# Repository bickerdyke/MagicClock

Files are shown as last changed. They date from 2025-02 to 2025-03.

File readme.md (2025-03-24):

# Magic Clock for Home Assistant

If you ever read or saw Harry Potter, you may remember the Weasley Family's magic clock that showed the whereabouts of all family members.
And of course you wanted something like that, too.

**Good News**: I built one and can share my work with you.

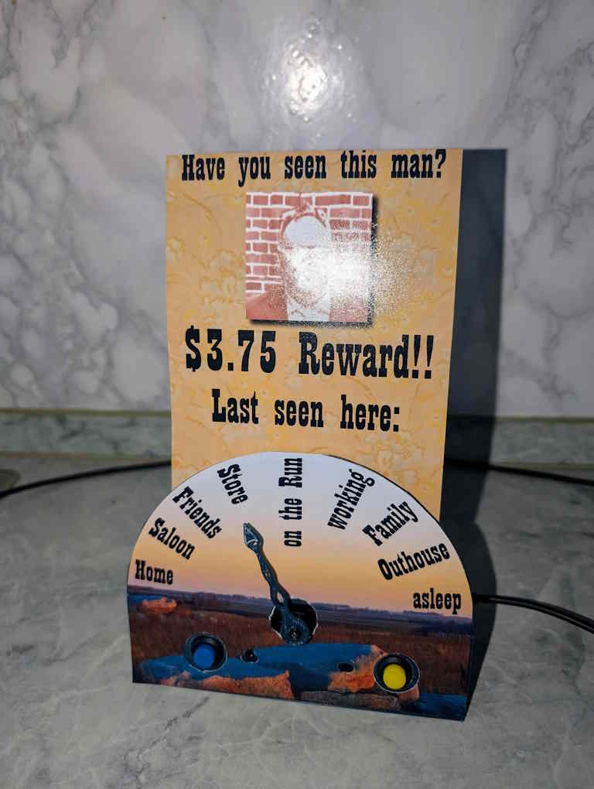
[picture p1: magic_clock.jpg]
Magic Clock Final


**Bad news**: You probably need to adjust each part of my work to your requirements. And it's several parts that need to work together.

The clock was meant to give my wive who had to go overseas for several months a way to connect back to me and home by getting live updates, but also make her presence felt by switching the living room light colors.

## Overview

This project uses a ESP32 to control a servo motor connected to a clock dial to display a persons current status. That status is based on several inputs like GPS data from phone, calendar data, a sleep state sensor or currently switched on Hue devices.

A local Home Assistant instance collects those data and decides where to point the clock dial, indicating locations like office or school, but also current activities like sleeping.

In addition, intended as a really simple way of two-way conversation, two switches control two LEDs that can be toggled on or off. The LED status is relayed back to the Home Assistant server and can be monitored and controlled from there, too.

## Requirements and Sub-Projects

It turned out that you need to combine several trades to build a magic clock. On the other hand, none of them went into the really advanced stuff and all the tools needed are free and Open Source.

- _[Smart Home Platform](homeassistant/)_: Home Assistant is used to collect all necessary data and control the clocks servo motor.
- _[CAD and 3D-Printing](CAD/)_: The case for the clock was designed using FreeCad
- _[Firmware and Network](esphome/)_: The EspHome-Project is far the easiest way to generate a firmware for ESP32 or similar that connects to Home Assistant
- _[Hardware](schematics/)_: Some sketches of the schematics
- _[Graphics & Design](Images/)_: Templates and measurements to help you designing your front plate for the magic clock. I used Scribus.

Detailed descriptions can be found in those folders.

## 3D-Printing

STL-Files for 3D-Printing the case are available on [printables.com](https://www.printables.com/model/1224639-magic-clock)

I will be happy to see your make results or comments there, too.

# Digital Twin

As an alternative to the actual clock with servo and physical dial, there is a simplified version included that uses a digital display. Building is much simpler as the only step neccessary is to clip an easily available esp32-2431S028 (or CYD - cheap yellow display) into a 3D-Printed parts (printable without any supports), flash the firmware and done. It uses a development board that contains both display and controller and the same Home Assistant back end as its "bigger" brother.

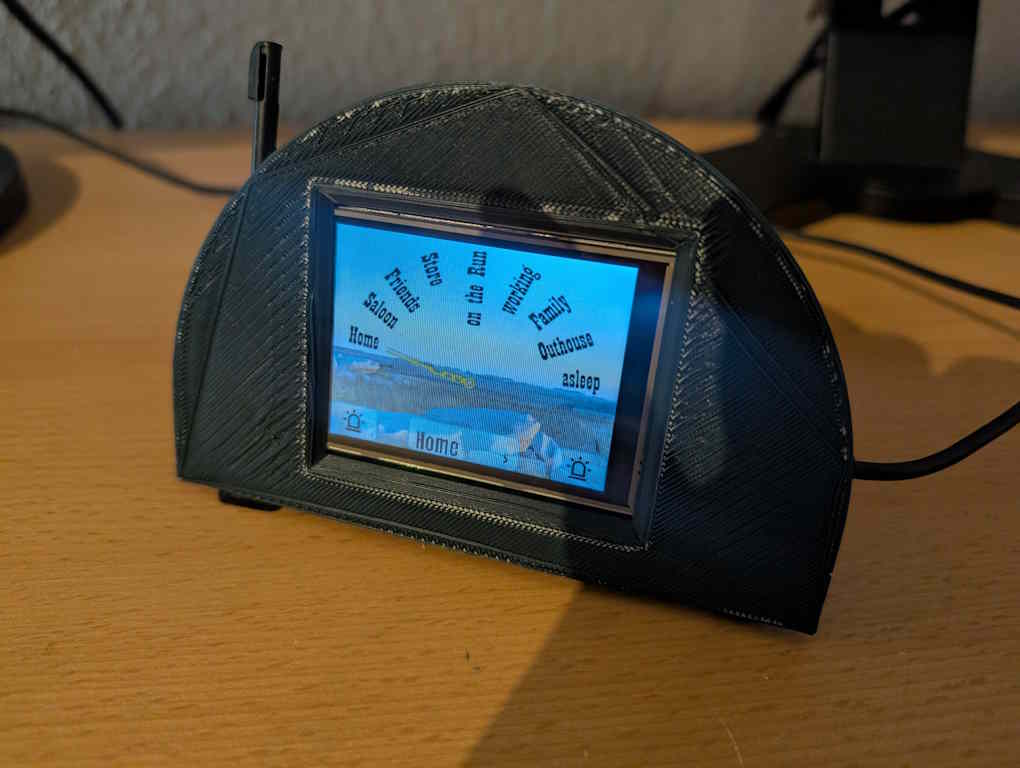
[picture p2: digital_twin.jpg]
Digital Twin


But with one exception: The included esphome configuration acts as a remote control for a "big" version. So it connects to the LED entities provided by the controlled device and has a drop down field to set the input_select entity in the backend that drives the clock hand. If you want to use _only_ a digital version you need to edit the firmware configuration to either provide entities for the two LEDs or add helpers in the back end and use those.

STL-Files for 3D-Printing the case of the digital twin are available on [printables.com](https://www.printables.com/model/1242070-magic-clock-with-display)

# Disclaimer

This is my personal hobby project and it is completely tailored to what I had already running, knew how to do or was ready to learn. Feel free to use my work as inspiration for your own and I would love to learn what you ended up making.

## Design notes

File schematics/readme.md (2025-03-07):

## Electronics

I'm very bad at electronics and soldering, so this part is probably the least complicated.

Central part is a ESP32 board. I had a ESP32 VROOM left from a previous project, but any microcontroller board that has Wifi included and is supported by [esphome](../esphome/) should do the trick.

The first prototype was working quickly:

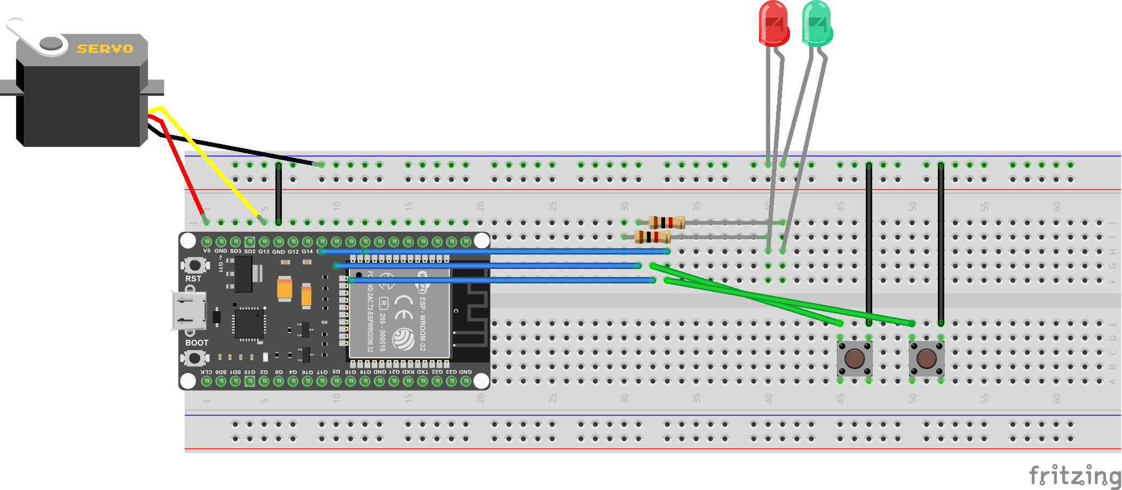
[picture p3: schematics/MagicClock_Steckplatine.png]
Breadboard sketch


A servo connected to 5V and GND for power and the PWM control to a GPIO pin that can output a PWM signal (check data sheet if using a different board) will drive the dial.

Two Buttons and two LEDs with resistors get also connected to a GPIO each. I started with 5mm LED and resistors from the junk drawer. For the final build, I used 3mm LED with integrated resistors that came with mounting rings for the case where the LEDs were supposed to click in for mounting. (50% success rate. Hot glue to the rescue!)

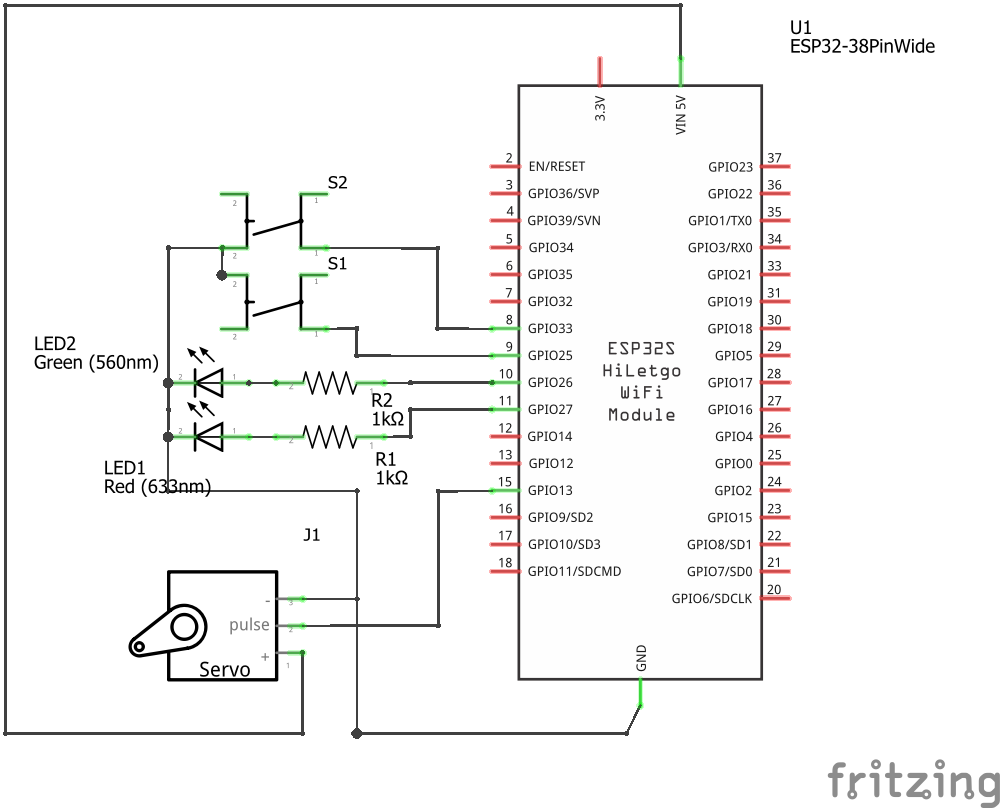
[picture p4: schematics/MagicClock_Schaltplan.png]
Circuit schematic


> [!IMPORTANT]
> I switched the GPIO pins during the assembly phase as using pins on both sides of the board made wiring easier. The pins on the schematic do not match the GPIO pins used in the final esphome configuration. You will need to adjust the configuration to whatever GPIOs you end up using.

You can find the [Fritzing](https://fritzing.org/) file included in this repo.

### Assembly

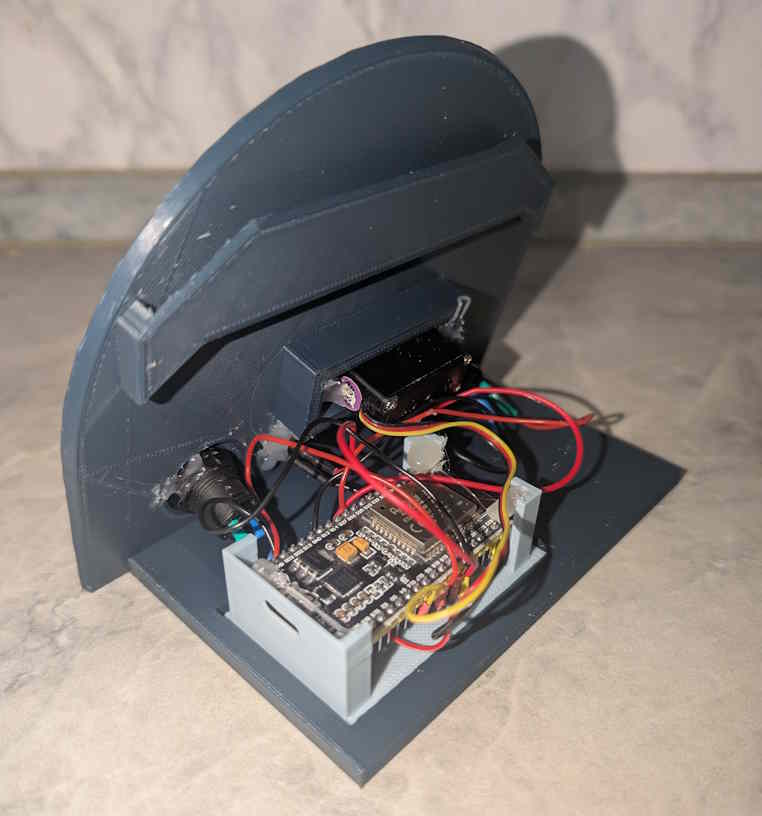
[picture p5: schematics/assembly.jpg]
Assembly


I used the terminals of the switched to connect GND for the matching LED so I only had 3 ground wires to attach to the ESP board that conveniently has the GND pins.

As mentioned in the beginning, I'm really bad at soldering so I covered up everything with the shrink tube of shame.

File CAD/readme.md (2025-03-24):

## Case design

With not much more tools than a 3d-Printer, I wanted the case to be as simple as possible and easily printable on a 15x15cm printer. Instead of a movement, I directly expose the servo motor and mount a dial on it. The clock face also needed space for the two buttons and LEDs.

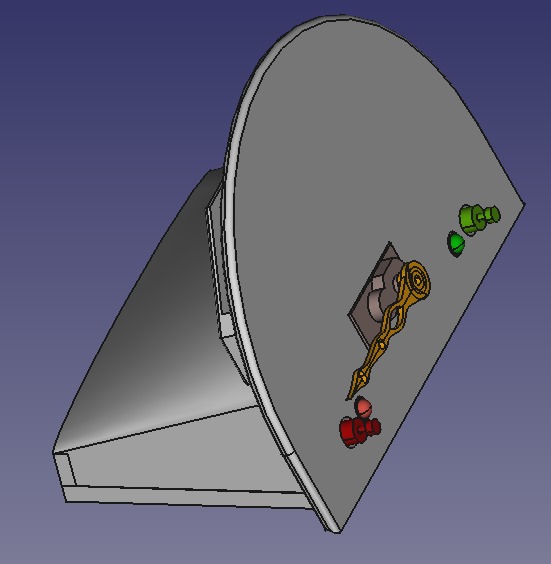
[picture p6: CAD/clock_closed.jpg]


The inside needed space to mount those things, plus the ESP board. The Board is mounted on a separate riser to simplify both printing and assembly, and maybe switch to a different type of board.

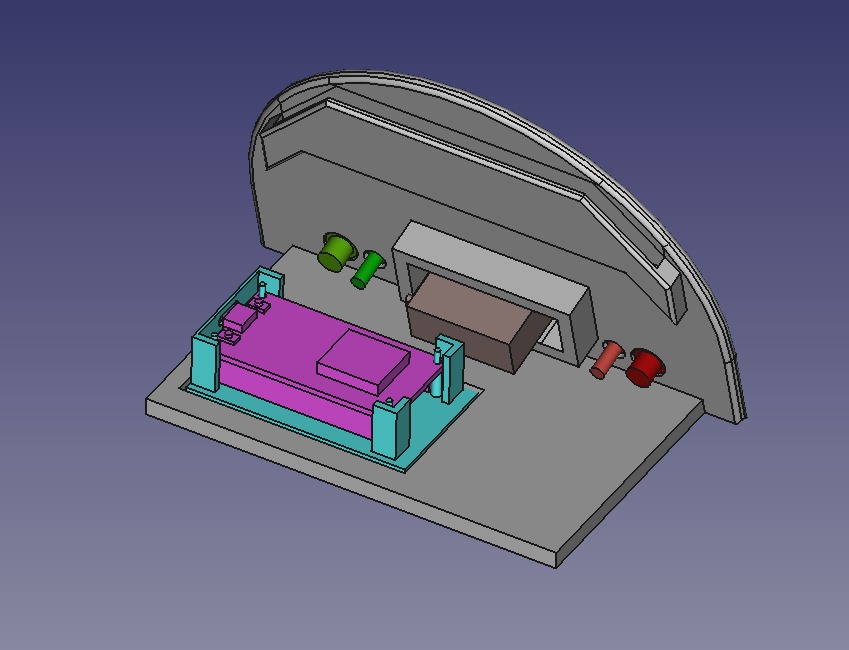
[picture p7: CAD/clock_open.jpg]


A slot to add a 11cm wide printed photo was added to the back.

### 3D Printing

Four parts need to be printed:

- Main case with clockface
- Cover
- ESP mounting plate
- Clock Dial

Case, Cover and mounting plate are simply glued together with hot glue. (Yes, _could_ have gotten a more elegant solution here...)

The Dial is screwed on the shaft of the servo using the screw that came with the motor

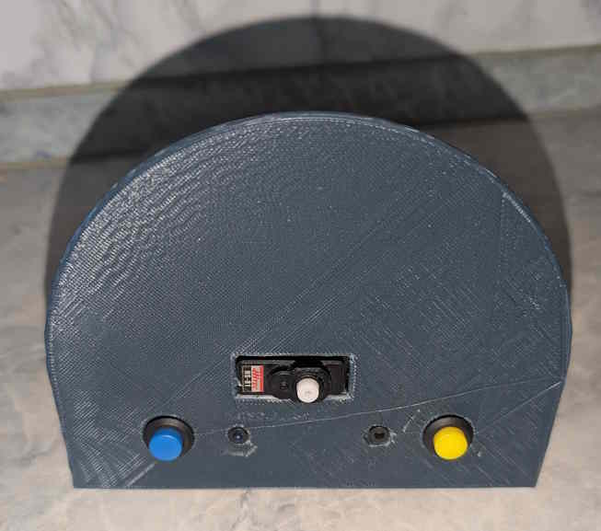
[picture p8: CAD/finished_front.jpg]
final assembly front


The front will be covered with a printed [clock face](../Images/).

## Digital Twin

It was supposed to be much smaller than the actual magic clock, but to hold the rectangular board with the display and keep the same shape as the full version, it ended up almost the same size:

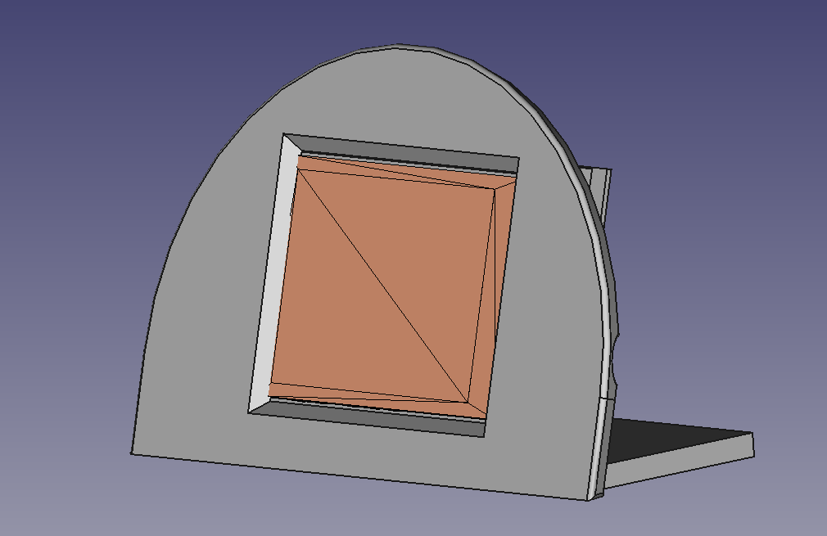
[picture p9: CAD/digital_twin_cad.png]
Digital Magic Clock CAD

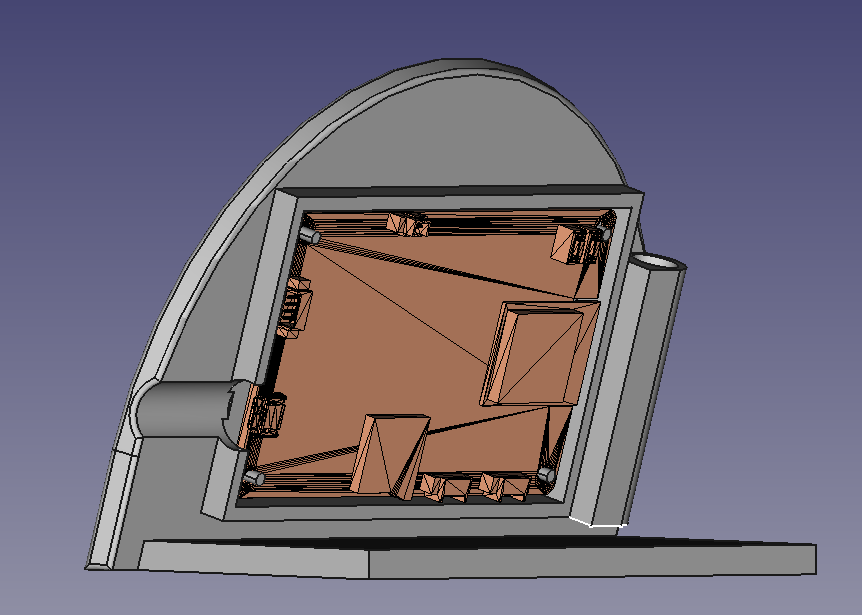
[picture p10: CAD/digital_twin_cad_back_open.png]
Digital Magic Clock CAD open


The model for the version with a digital display uses a transparent back to hold the display in place and keep the included RGB LED visible. There is also a holder for a pen that came with my display.

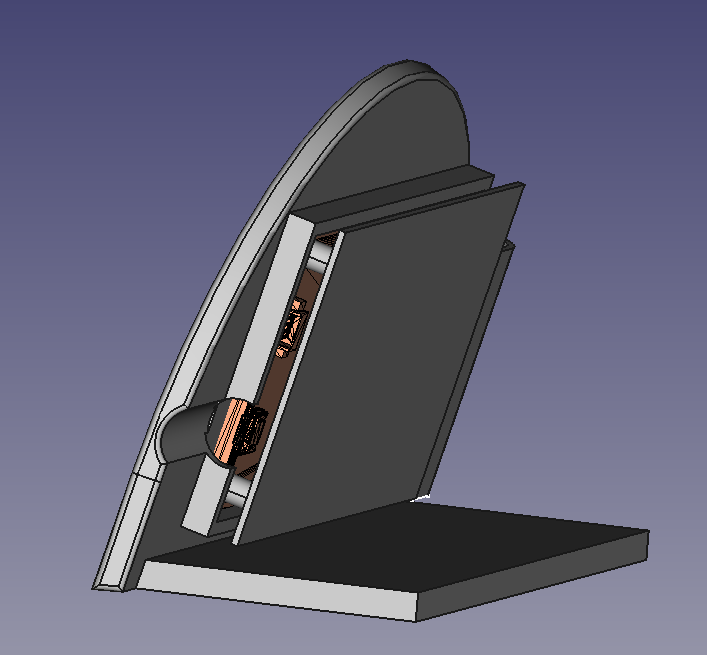
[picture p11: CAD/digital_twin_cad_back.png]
Digital Magic Clock CAD back

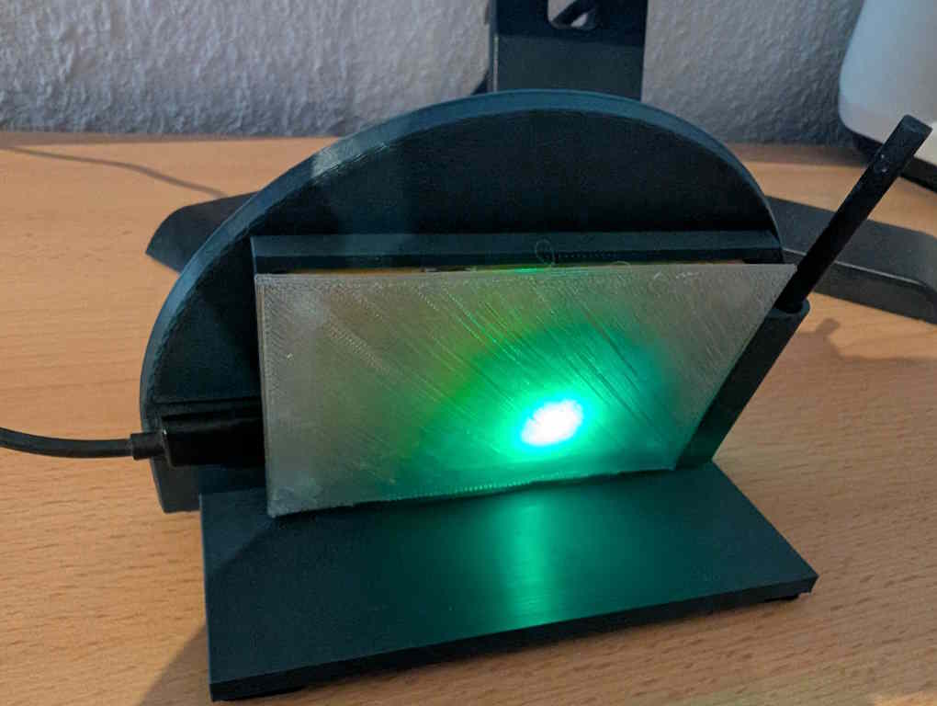
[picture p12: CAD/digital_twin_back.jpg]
Digital Magic Clock Backside


## Individual Adjustments

In case you want to do your own improvements and adjustments, I included the [FreeCAD](https://www.freecad.org/) model file in this repo. It's a free and open source CAD system.

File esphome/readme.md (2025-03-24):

## Firmware

The whole Magic Clock system is controlled by an ESP32 Wroom board with an [esphome](https://esphome.io/) firmware. It offers many features out of the box that we need:

- Servo Control
- LED / Switch Controls
- Home Assistant API support
- Wifi
- Wifi configuration in your webbrowser
- VPN

esphome takes a configuratuon file for your project and compiles a firmware for several microcontroller platforms. The configuration file for the Magic Clock is [magic-clock.yaml](magic-clock.yaml). You may need to adjust the file from this repo to your project.

### Setup

esphome can either use stores credentials to connect to a Wifi network, or, if no such network can be found, will open a configuration wifi network that you can connect to with your phone and set up your wifi. An optional password can be set in the configuration. Default configuration for the setup-wifi is ssid _Magic-Clock Setup_ with password _Foxtrott1308_

Current configuration has two slots for pre-installed wifi networks. Actual credentials will be read from a secrets.yaml file

- [Wifi configuration documentation](https://esphome.io/components/wifi.html)
- [Captive Portal documentation](https://esphome.io/components/captive_portal.html)

#### Secrets.yaml

Configuration and credentials should be kept separate. The included configuration will pull wifi and other credentials from a secrets.yaml file in the same directory as the configuration file. You can use the provided example to create your own secrets.yaml-file.

#### Home Assistant and alternatives

esphome integrates natively with Home Assistant or ioBroker.

[Home Assistant API Documentation](https://esphome.io/components/api.html) This link will also generate a random key for you that you can include in your secrets.yaml to encrypt communication between Home Assistant and the Magic Clock. Home Assistant will ask for this key, too when adding it as a device.

If you want to use some a different software stack you can also configure esphome to include a webservice or [MQTT](https://esphome.io/components/mqtt.html) connection to accept commands to set the dial to any given position.

#### Hardware configuration

As you will probably use different pins then my build, you will need to edit the configuration to match your build. You can find the documentation for those configuration sections here:

- [Status Led](https://esphome.io/components/status_led.html)
- [Switch](https://esphome.io/components/switch/) LED hardware configuration. Will be exposed to Home Assistant
- [Binary Sensor](https://esphome.io/components/binary_sensor/) Pushbuttons. Will be exposed to Home Assistant
- [Output](https://esphome.io/components/output/#output) and [Servo](https://esphome.io/components/servo.html)
- [Number](https://esphome.io/components/number/) Will be exposed to Home Assistant. Includes the logic to control the servo motor (using esphome Servo component) when this value is changed in Home Assistant.

### VPN

In my setup, the Magic Clock will not be in the same network as my Home Assistant Server. (Actually, it will be on a different continent) As Home Assistant will use the esphome integration to connect to the Magic Clock (and not the other way round), the Clock needs to be reachable for your Home Assistant server in your home network.

To solve that problem, esphome includes a client for the wireguard vpn.

My router supports giving access to my local network to external devices using the wireguard protocol, too, so I set up wireguard VPN access to my home network. The credentials and settings that I have been provided here go to the _wg_ section of the configuration file. (directly or via secrets.yaml)

See the esphome [Wireguard component](https://esphome.io/components/wireguard.html) documentation for details and peer setup guide.

If you will have the Magic Clock in the same network as your Home Assistant server, you can remove the wireguard setup by removing the _wg:_ section from the configuration.

## Installation

Behind the scenes, esphome will take your configuration file and compile an individual firmware file for your micro controller platform. This firmware needs to be programmed into your controllers firmware memory. For the first time, this requires a USB connection to your computer. Later updates can be installed Over the Air [(OTA)](https://esphome.io/components/ota/esphome.html)

The Installation guide at [https://esphome.io/guides/getting_started_hassio](https://esphome.io/guides/getting_started_hassio) will guide you through installing the esphome Device builder as a Home Assistant Plugin and create and flash your first esphome firmware. If you can't install Home Assistant pluginst, esphome can be run as a [docker container](https://esphome.io/guides/getting_started_command_line#esphome-device-builder-docker).

Both options will give you access to the esphome Device manager in your webbrowser where you can add your Magic Clock as a device and upload your individual configuration file, create a firmware file based on it and flash that file on the micro controller.

For further help on esphome check out the Guides and FAQs and tips available on the [esphome homepage](https://esphome.io/).

## Digital Twin

The esphome configuration for the digital twin is found in the file [display.yaml](display.yaml). It acts as a remote control for a "big" version. So it connects to the LED entities provided by the controlled device and has a drop down field to set the input_select entity in the backend that drives the clock hand. If you want to use _only_ a digital version you need to edit the firmware configuration to either provide entities for the two LEDs or add helpers in the back end and use those.

Also, it does _not_ include a Wireguard configuration as that device is staying within my wifi. But you can set it up in the same way as it is included in magic-clock.yaml

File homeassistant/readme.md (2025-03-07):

## Home Assistant

I had already a working Home Assistant, so it was just natural to use it as the central hub to control the magic clock.

Home Assistant can use the companion app on users phones to collect location data and access all other kind of information to factor into your magic clock and on the other end can use [esphome](../esphome/readme.md) to connect and control the clock.

When connected to the device, it will expose these entities to Home Assistant:

- A number setting that controls the angle of the clock dial. The servo has a range of 180° that is represented as a number range from -100 to 100 with 0 being the middle position.
- 2 switches representing the LEDs
- 2 binary sensors representing the buttons.

Now we can unleash the power of Home Assistant... The yaml files in this directory will show you how I did it.

### Helpers

[helper.yaml](helper.yaml) sets up an input select helper listing all the labels available on the clock face and an input boolean helper to quickly enable or disable automatic movement of the clock dial.

### Dial control

[automation_set_dial_position.yaml](automation_set_dial_position.yaml) connects the selection helper to the servo motor. Each time a new option is selected by the helper, this automation will set the angle of the servo motor accordingly. The stepping for the angle control number entity in theory should be +-100 / number of labels, but in the end depends on your clockface design. Use try and error to find out which values look good and point exactly at your labels.

[automation_set_dial_label.yaml](automation_set_dial_label.yaml) This is where the magic happens. All kind of input is used to decide which label to point to:

- GPS fencing from the companion app will result in a location based labels such as "shop", "friends" or "bar"
- Events from my Google calendar will show "Working" while in meetings
- Hue lamps switched on or off are used as a substitute presence indicator for certain rooms.
- A different (existing) status helper signals sleep or awake and general presence or absence.
  If you want to use my design and turn it into a weather station or something completely different, this is the spot where you need to change to your logic.

### Buttons and LEDs

The clock has two buttons (blue and yellow) that toggle the two LEDs next to the buttons on the clockface. (also blue and yellow) Nice but not spectacular. But we can turn that into a low level 2-way communication device:

[dashboard_signal_buttons.yaml](dashboard_signal_buttons.yaml) gives an example for how to add buttons to your Home Assistant Dashboard that will

1. Show the LED status in your dashboard
1. Allow to remote control the LEDs manually

Feel free to add any semantics to those two lights. Switch on the yellow light for "Dinner is ready" and the blue one for "call me" or whatever fits the point of your magic clock.

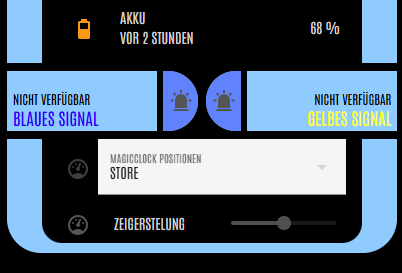
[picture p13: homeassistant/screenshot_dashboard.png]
Dasbhoard Buttons


[automation_show_clock_signal.yaml](automation_show_clock_signal.yaml) To make sure I notice when the buttons on the clock are pressed, a Hue lamp in the living room will match the color of the pressed button. Phone notifications through the Companion App or Emails or logging would go in here, too.

### Source

You can get Home Assistant at [https://www.home-assistant.io/](https://www.home-assistant.io/), but you also could use any other way of controlling the clock by using a different esphome configuration.

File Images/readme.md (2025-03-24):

## Images

The Magic Clock gets its appearance mostly from two images: The clockface and the (optional) picture in the picture holder on the back.

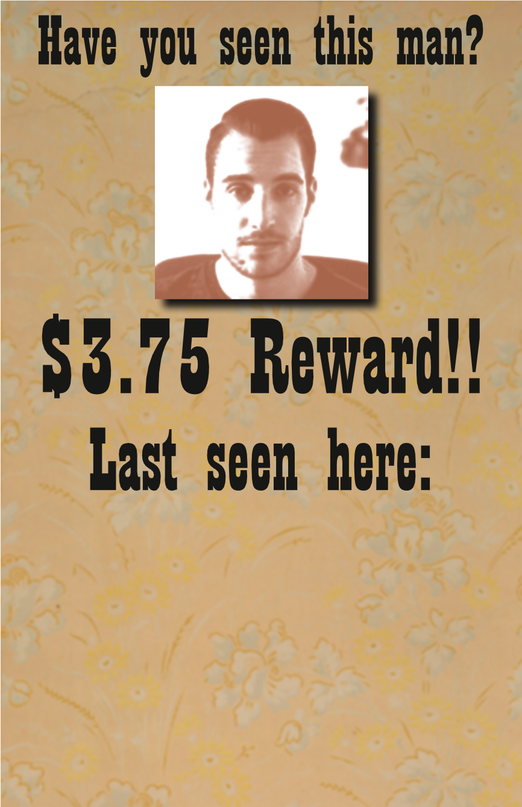
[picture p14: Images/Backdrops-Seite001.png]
Backdrop 1

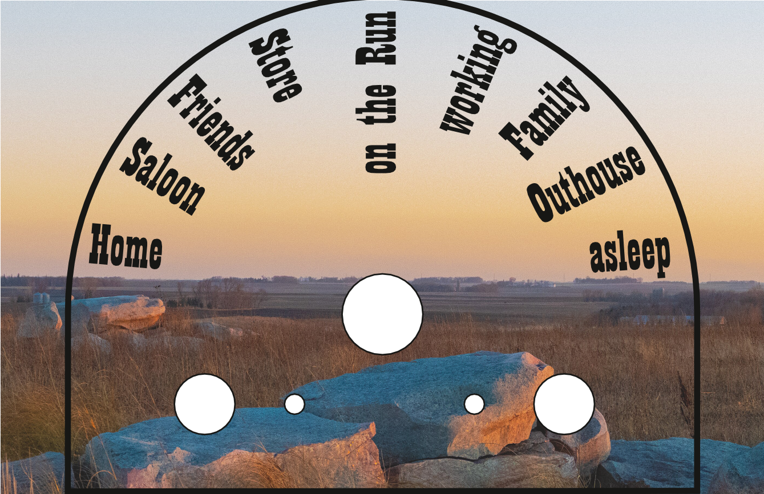
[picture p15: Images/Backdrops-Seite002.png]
Backdrop 2


Both are created as 11x17cm images that is available as a standard photo size (and can be printed out on actual photo stock) and roughly matches the 15x15cm limits of my 3d-Printer.

They were created using [Scribus](https://www.scribus.net/), free and open source DTP software, in case you want to build on my pictures and go from there.

Or if you want to use your favorite graphic suite, you can use these measurements as a guideline:

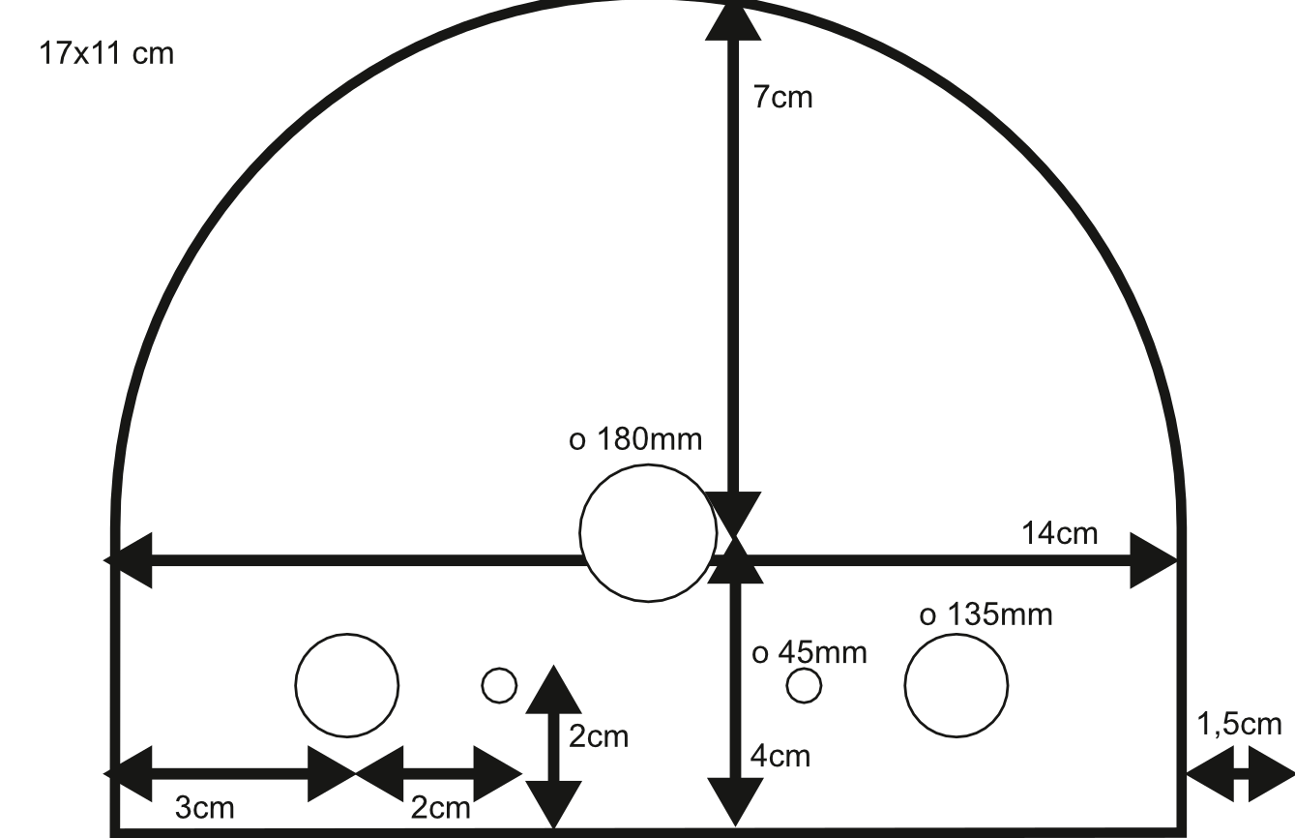
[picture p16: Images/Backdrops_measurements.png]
Measurements


### Sources

#### Font
[Playbill](https://learn.microsoft.com/de-at/typography/font-list/playbill), 75pt, part of the MSOffice package

#### Image

I used images available on Wikimedia Commons, so I won't include them in this repo. You can get them here if you want to use them, too.

* Sidewall (USA), 1905–15, Made by Janeway & Co. Inc. [2048px-Sidewall_(USA),_1905–15_(CH_18500779).jpg](https://commons.wikimedia.org/wiki/File:Sidewall_(USA),_1905%E2%80%9315_(CH_18500779).jpg) Wikemedia Commons, Public Domain

* Evening on the prairie, Rock County, Minnesota [4096px-Evening_on_the_prairie,_Rock_County,_Minnesota.jpg](https://commons.wikimedia.org/wiki/File:Evening_on_the_prairie,_Rock_County,_Minnesota.jpg) Wikimedia Commons, Creative Commons Attribution 2.0 Generic license, work by Sank63 from [https://www.flickr.com/photos/gsankary/53341044031/]

#### Dummy-User
The person used here is a dummy user profile picture created by [https://randomuser.me/photos](https://randomuser.me/photos)

### Digital Dial
The dial for the digital twin of the clock is based on [Clock2](https://commons.wikimedia.org/wiki/File:Clock2.svg) by Wikipedia-User [Fornax](https://commons.wikimedia.org/wiki/User:Fornax) licensed under the Creative Commons Attribution-Share Alike 3.0 Unported license.

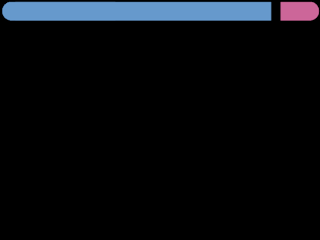
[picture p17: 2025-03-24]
esphome/images/lcars-wallpaper1.png

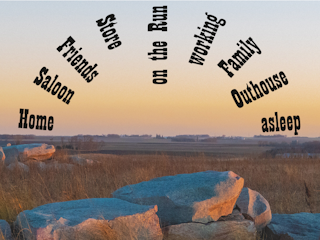
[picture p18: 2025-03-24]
esphome/images/magic-clock.png

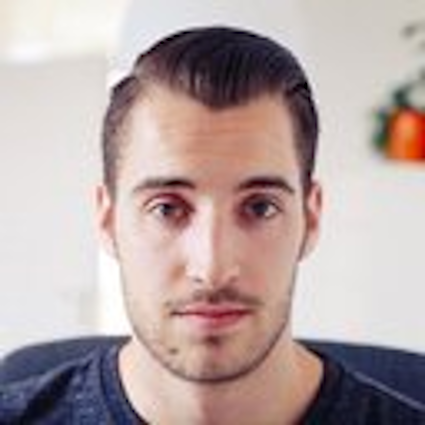
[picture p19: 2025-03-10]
Images/mugshot.jpg

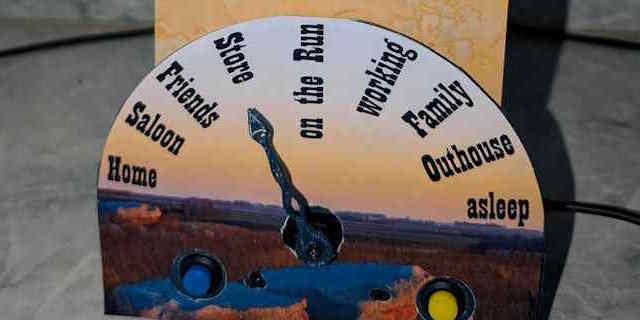
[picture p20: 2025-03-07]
magic_clock - social.jpg

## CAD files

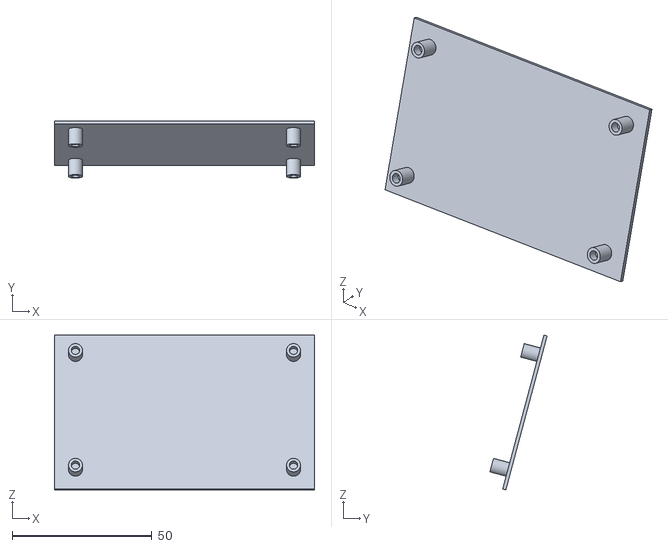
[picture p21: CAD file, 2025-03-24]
CAD/DigitalTwin-Abdeckplatte.stl
93.0 x 20.5 x 55.4

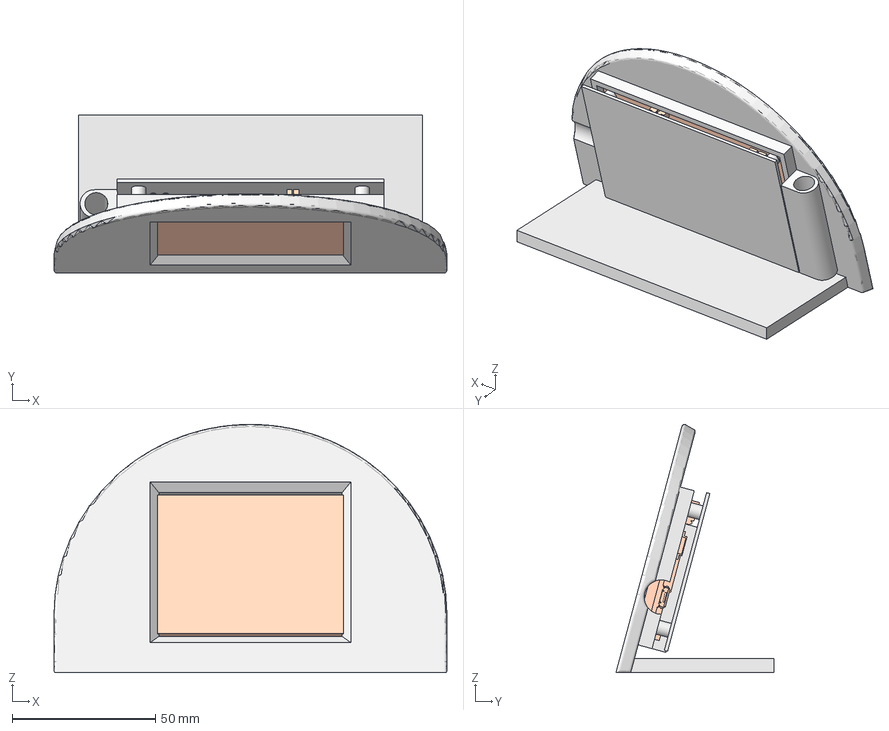
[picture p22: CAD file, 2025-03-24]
CAD/DigitalTwin.FCStd
137.1 x 55.2 x 86.6 mm
ClockFace
Abdeckplatte
2.8inch_LCD_Model

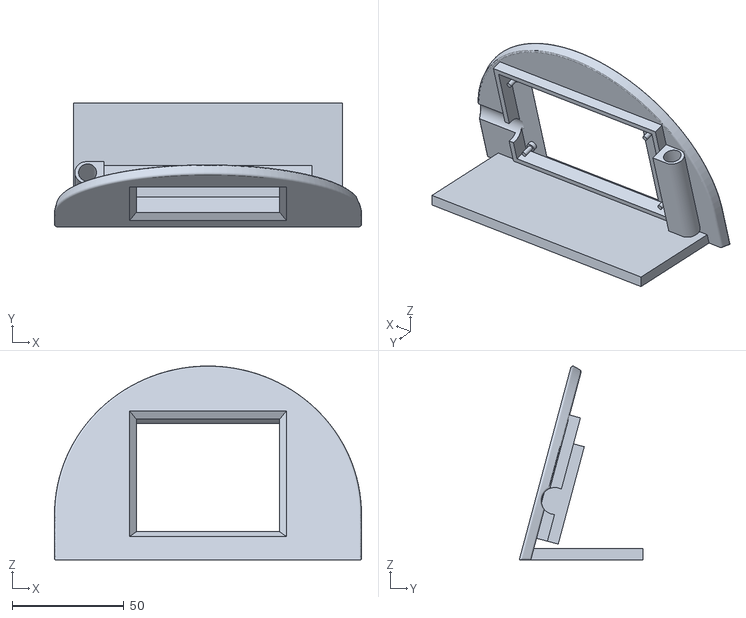
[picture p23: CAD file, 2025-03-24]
CAD/DigitalTwin-ClockFace.stl
137.1 x 55.2 x 86.6

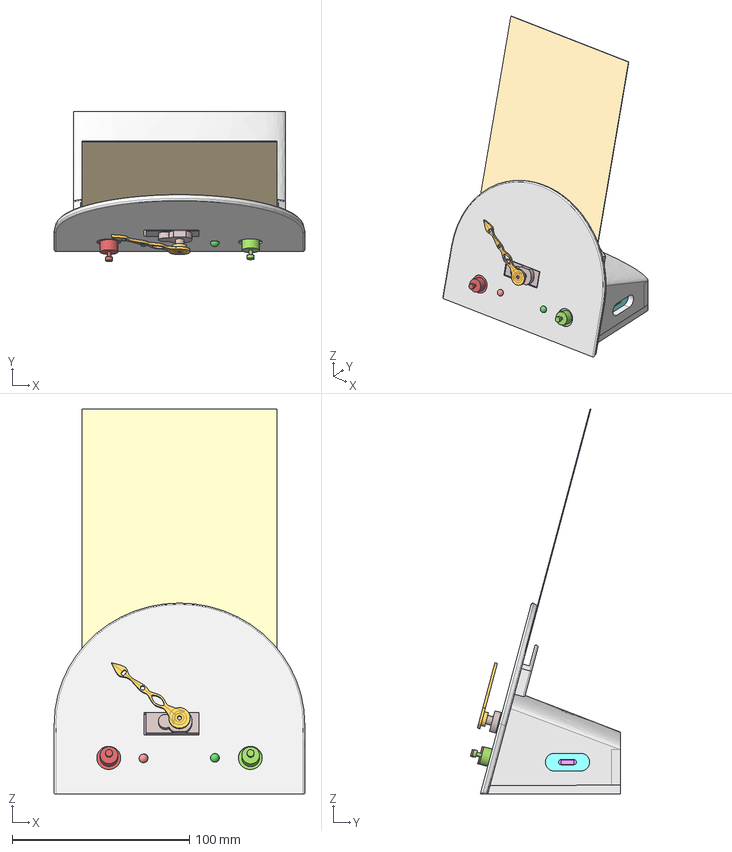
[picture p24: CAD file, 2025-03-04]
CAD/MagicClock.FCStd
141.6 x 84.8 x 217.5 mm
ClockFace
ServoDummy
LedDummy
LedDummyGreen
SwitchDummy
SwitchDummyGreen
EspDummy
Platinentraeger
Deckel
FotoDummy
Zeiger

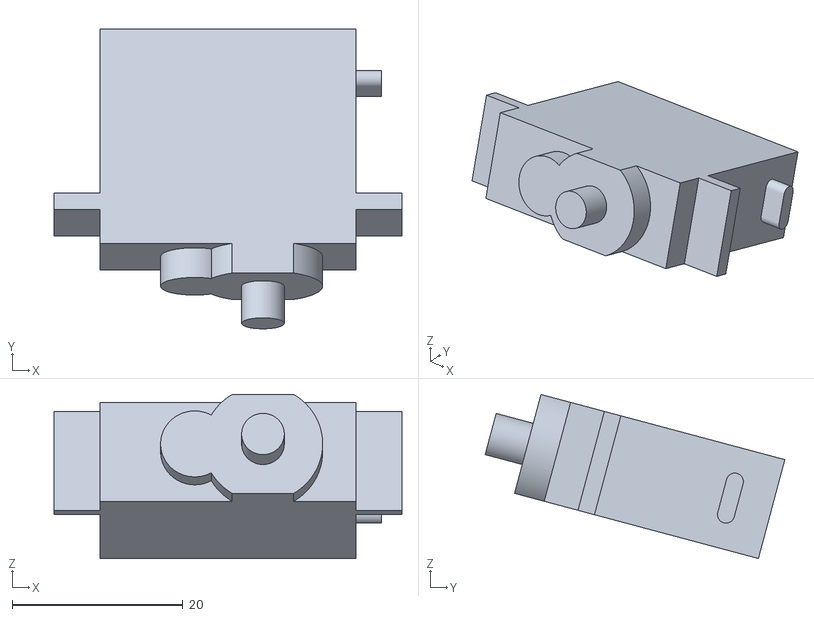
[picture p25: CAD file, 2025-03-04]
CAD/MagicClock-ServoDummy.stl
40.8 x 35.1 x 19.2

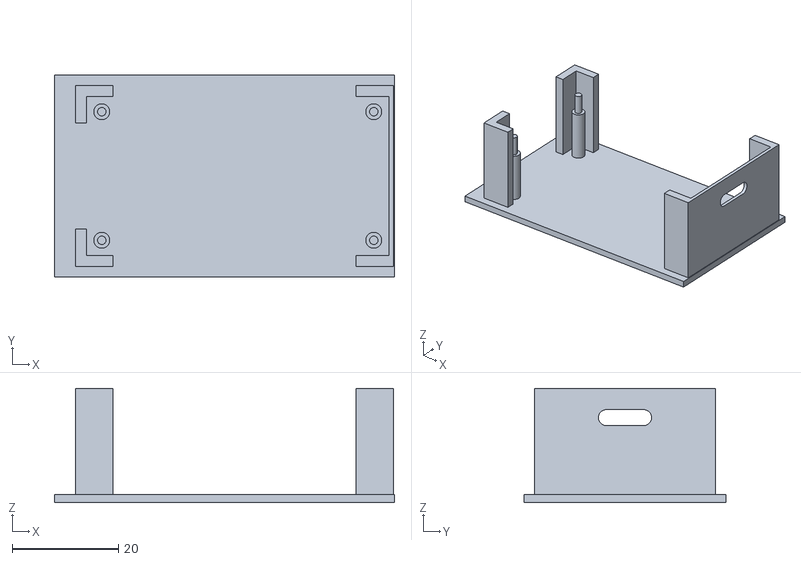
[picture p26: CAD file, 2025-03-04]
CAD/MagicClock-Platinentraeger.stl
64.0 x 38.0 x 21.5

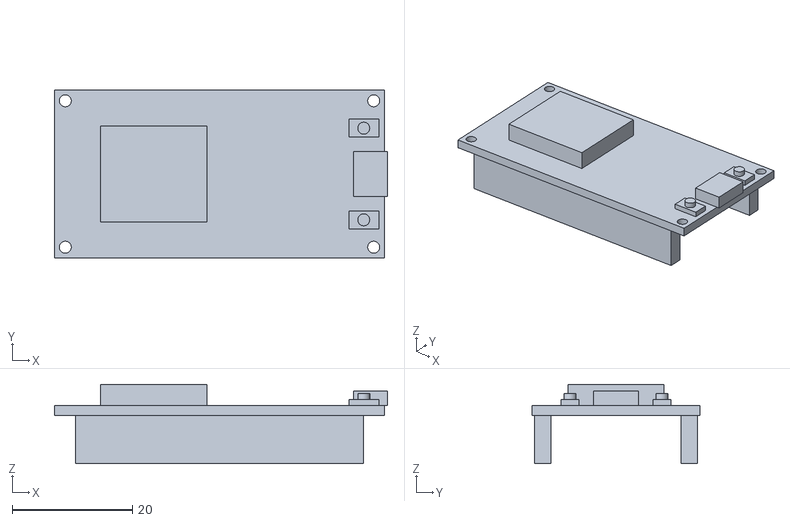
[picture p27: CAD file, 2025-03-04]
CAD/MagicClock-EspDummy.stl
55.5 x 28.0 x 13.2

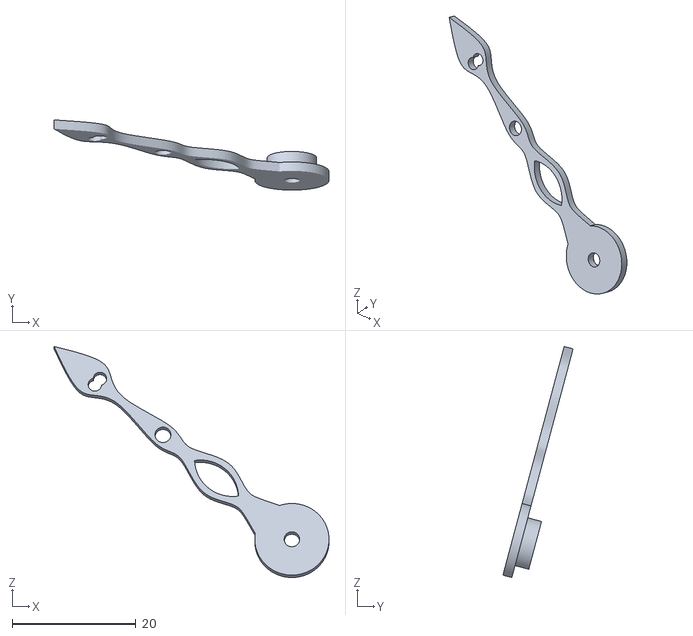
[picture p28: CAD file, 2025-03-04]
CAD/MagicClock-Zeiger.stl
44.5 x 11.4 x 37.4

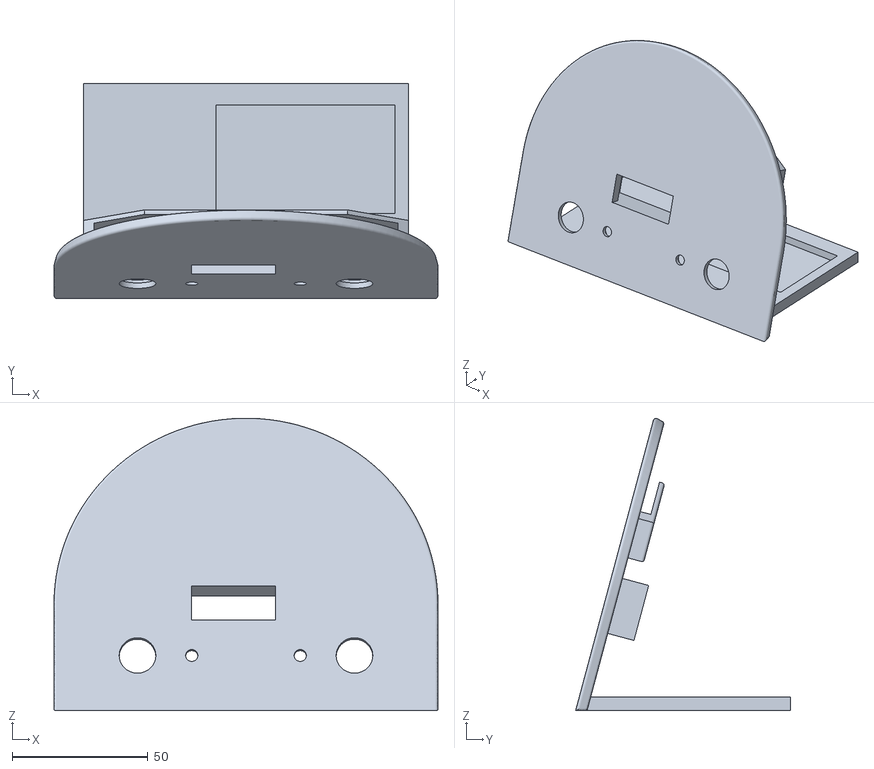
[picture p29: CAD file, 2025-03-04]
CAD/MagicClock-ClockFace.stl
141.6 x 79.2 x 107.8

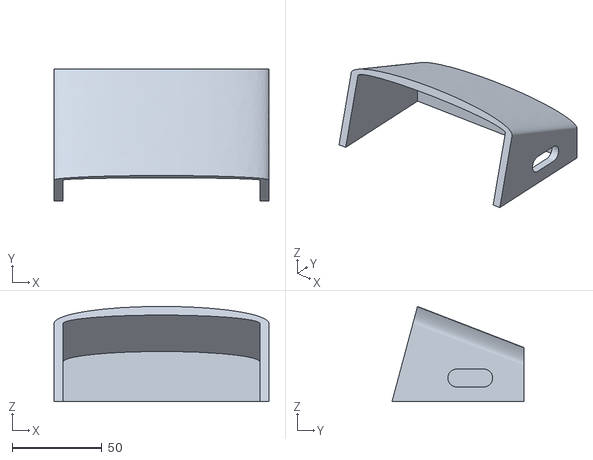
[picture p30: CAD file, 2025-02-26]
CAD/MagicClock-Deckel.stl
120.0 x 73.7 x 53.1

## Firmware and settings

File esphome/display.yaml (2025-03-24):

#
# Basic yaml code to get the ESP32-2432S028R display to work in ESPHome.
# https://github.com/witnessmenow/ESP32-Cheap-Yellow-Display/tree/main/Examples/ESPHome
#

# ============================================================
# Example file setup
# Change the naming below, they will be the names used in Home Assistant
#
substitutions:
  device_name: yellowtft1
  friendly_name: Yellow TFT 1

# ============================================================
# Standard ESPHome setup
#
# ESPHome naming
esphome:
  name: $device_name
  friendly_name: $friendly_name
  on_boot:
    - priority: 0
      then:
        lvgl.page.show:
          id: p_clock

esp32:
  board: esp32dev
  framework:
    type: arduino

# Enable logging
logger:

# Enable Home Assistant API
api:
  encryption:
    key: !secret display_ApiKey

ota:
  platform: esphome
  password: !secret display_OtaSecret

wifi:
  networks:
    - ssid: !secret wifi_ssid
      password: !secret wifi_password

  # Enable fallback hotspot (captive portal) in case wifi connection fails
  ap:
    ssid: "Display Setup"
    password: "Foxtrott1308"

captive_portal:

time:
  - platform: homeassistant
    id: esp_time
    timezone: Europe/Berlin
    on_time:
      - minutes: /15
        seconds: 27
        then:
          - lvgl.label.update:
              id: lbl_date
              text:
                time_format: "%a %F"
                time: !lambda return id(esp_time).now();
      - minutes: /1
        seconds: 0
        then:
          - lvgl.label.update:
              id: lbl_time
              text:
                time_format: "%H:%M"
                time: !lambda return id(esp_time).now();
      - seconds: 15, 45
        then:
          - if:
              condition:
                lambda: return id(auto_cycle).state && !id(flag_inUse);
              then:
                - lvgl.page.next:
      - seconds: /1
        then:
          - lvgl.bar.update:
              id: bar_seconds
              value: !lambda return id(esp_time).now().second;

# ============================================================
# ESPHome Display related setup
#
# Create a font to use, add and remove glyphs as needed.

font:
  - file:
      type: gfonts
      family: Antonio
      weight: bold # thin, light, regular medium, bold....
    id: lcars_24
    size: 24 # default: 20
    glyphsets: [GF_Latin_Core]
    glyphs: ["\u203A"]

  - file:
      type: gfonts
      family: Antonio
      weight: bold # thin, light, regular medium, bold....
    id: lcars_48
    size: 48
    glyphsets: [GF_Latin_Core]
    glyphs: ["\u203A"]

# Create a Home Assistant blue color
color:
  - id: color_ha_blue
    hex: 51c0f2
  - id: color_clock_buttonborder
    hex: 135a7a
  - id: color_light_gray
    hex: dedcd7
  - id: color_blue
    hex: 2667d1
  - id: color_yellow
    hex: d4c60d

# Background images
image:
  - file: "images/lcars-wallpaper1.png"
    id: bg_lcars
    type: RGB565
  - file: "images/magic-clock.png"
    id: bg_magicclock
    type: RGB565
  - file: "images/Clock2.svg"
    id: img_magicclock_dial
    type: RGB565
    resize: 13x107
    transparency: alpha_channel

  - file: mdi:alarm-light-outline
    id: icon_alert
    type: grayscale
    transparency: alpha_channel
    resize: 30x30

# ============================================================
# Home Assistant related setup
#

globals:
  - id: magicclock_statuses
    type: std::vector<std::string>
    initial_value: '{"Home","Saloon","Friends","Store","on the Run","working","Family","Outhouse","asleep"}'
  - id: magicclock_angles
    type: std::vector<int>
    initial_value: "{280, 298, 316, 335, 358, 22, 40, 59, 78}"
  - id: flag_inUse
    type: boolean
    initial_value: "false"

select:
  - platform: template
    id: sel_displayPage
    name: Seite
    icon: mdi:vector-arrange-below
    options:
      - Splash
      - Clock
      - Magic Clock
    optimistic: true
    on_value:
      - if:
          condition:
            lambda: return (x == "Splash");
          then:
            - lvgl.page.show:
                id: p_splash
      - if:
          condition:
            lambda: return (x == "Clock");
          then:
            - lvgl.page.show:
                id: p_clock
      - if:
          condition:
            lambda: return (x == "Magic Clock");
          then:
            - lvgl.page.show:
                id: p_magicclock

number:
  - platform: template
    name: LVGL Screen timeout
    optimistic: true
    id: display_timeout
    unit_of_measurement: "min"
    initial_value: 60
    restore_value: true
    min_value: 3
    max_value: 180
    step: 1
    mode: box

switch:
  - id: auto_cycle
    platform: template
    optimistic: true
    name: Autoimatischer Seitenwechsel
    icon: mdi:animation
    restore_mode: ALWAYS_ON
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

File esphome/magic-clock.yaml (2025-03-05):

esphome:
  name: magic-clock
  friendly_name: Magic Clock
  on_boot:
    then:
      - delay: 4s
      - servo.write:
          id: servo_dial
          level: 100%
      - delay: 4s
      - servo.write:
          id: servo_dial
          level: -100%
      - delay: 4s
      - servo.write:
          id: servo_dial
          level: 0%

esp32:
  board: esp32dev
  framework:
    type: arduino

# Enable logging
logger:

# Enable Home Assistant API
api:
  encryption:
    key: !secret magicclock_ApiKey

ota:
  password: !secret magicclock_OtaSecret

wifi:
  networks:
    - ssid: !secret wifi_ssid
      password: !secret wifi_password
    - ssid: !secret redlion_wifi_ssid
      password: !secret redlion_wifi_password

  # Enable fallback hotspot (captive portal) in case wifi connection fails
  ap:
    ssid: "Magic-Clock Setup"
    password: "Foxtrott1308"

captive_portal:

time:
  - platform: sntp
    id: sntp_time

wireguard:
  private_key: !secret magicclock_privatekey
  peer_preshared_key: !secret magicclock_presharedkey
  address: 192.168.42.202
  netmask: 255.255.255.0
  peer_endpoint: !secret magicclock_wg_endpoint
  peer_port: 51068
  peer_public_key: !secret magicclock_publickey
  peer_persistent_keepalive: 55s
  update_interval: 45s
  peer_allowed_ips:
    - 192.168.42.0/24
    - 0.0.0.0/24

# GPIO Funktion	 Breadboard-Pin
# 5V: --> Servo 		--> 1
# GPIO17: PWM Servo -
# GND: Masseschiene	--> 6
# GPIO27: LED 1		--> 9		--> 30
# GPIO21: LED 2		--> 10		--> 31
# GPIO25: Switch 1	--> 11		--> 32
# GPIO18: Switch 2	--> 12		--> 33

status_led:
  pin: GPIO2 # onboard LED

switch:
  - platform: gpio
    pin: GPIO27
    name: Light Blue
    id: led_blue

  - platform: gpio
    pin: GPIO21
    name: Light Yellow
    id: led_yellow

binary_sensor:
  - platform: gpio
    pin:
      number: GPIO25
      inverted: true
      mode:
        input: true
        pullup: true
    name: "Button Blue"
    id: button_blue
    #device_class: none # default: none
    on_release:
      then:
        - switch.toggle: led_blue

  - platform: gpio
    pin:
      number: GPIO18
      inverted: true
      mode:
        input: true
        pullup: true
    name: "Button Yellow"
    id: button_yellow
    #device_class: none # default: none
    on_release:
      then:
        - switch.toggle: led_yellow

# Servo Configuration

output: # physical servo output
  - platform: ledc
    id: servo_pwm_output
    pin: GPIO17
    frequency: 50 Hz

servo: # servo component
  - id: servo_dial
    output: servo_pwm_output
    #min_level: 3.2%
    #max_level: 11.8%
    transition_length: 1.5s
    #auto_detach_time: 5s

number: # Homneassistant Entity controlling servo
  - platform: template
    name: Zeigerstellung
    id: zeiger
    min_value: -100
    initial_value: 0
    max_value: 100
    step: 2
    optimistic: true
    set_action:
      then:
        - servo.write:
            id: servo_dial
            level: !lambda "return x / 100.0;"
        - delay: 3s
        - if:
            condition:
              not:
                - number.in_range:
                    id: zeiger
                    above: -75.0
                    below: 75.0
            then:
              - logger.log: "detaching servo in End-position"
              - servo.detach: servo_dial

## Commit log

2025-02-17 Construction File for Clock Body
    [MagicClock.FCStd]
2025-02-17 Added Platinenträger
    [MagicClock.FCStd]
2025-02-18 Deckel und Bodenplatte
    [MagicClock.FCStd]
2025-02-18 Neuer Platinenhalter, Aussparung
    [MagicClock.FCStd]
2025-02-18 Fotohalter Finished
    [MagicClock.FCStd]
2025-02-18 Cad Complete
    [MagicClock.FCStd]
2025-02-20 größere Aussparung für USB-Stecker
    [MagicClock.FCStd]
2025-02-20 Added STL-files
    [MagicClock-ClockFace.stl, MagicClock-Deckel.stl, MagicClock-EspDummy.stl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]
2025-02-21 Schaltpläne
    [MagicClock.fzz]
2025-02-21 Fix Fotohalter
    [MagicClock-ClockFace.stl, MagicClock.FCStd]
2025-02-21 Fix Zeiger
    [MagicClock-Zeiger.stl, MagicClock.FCStd]
2025-02-24 Fotohalter gekürzt
    [MagicClock-ClockFace.stl, MagicClock.FCStd]
2025-02-24 Improved servo motor detachment
2025-02-25 fix Servo-brumm added calendar trigger
    [magic-clock.yaml]
2025-02-26 Adjusted Clock size
    [MagicClock-ClockFace.stl, MagicClock-Deckel.stl, MagicClock-Platinentraeger.stl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]
2025-03-03 Changed LED colors, switched pins, added 2nd wifi
2025-03-04 Update sizes and new switches
    [MagicClock-ClockFace.stl, MagicClock-EspDummy.stl, MagicClock-Platinentraeger.stl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]
2025-03-05 servo stepping
2025-03-07 Added schematics and final image
2025-03-08 CAD instructions
2025-03-24 Added digital twin
    [DigitalTwin-Abdeckplatte.stl, DigitalTwin-ClockFace.stl, DigitalTwin.FCStd]
2025-03-24 Added digital twin documentation
    [DigitalTwin.FCStd]
